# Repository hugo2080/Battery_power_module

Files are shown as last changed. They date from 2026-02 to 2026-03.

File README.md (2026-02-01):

# Battery_power_module



Battery power module for bathroom scale

Place a 0.7 V forward voltage rectifier diode, e.g. 1N4007, between pin 2 of connector J2 and VDD of the MCU board, with the anode facing J2, to reduce the voltage to a safe 3.6 V.

## Licensing

This project is released under the **CERN Open Hardware Licence v1.2**.

* **Hardware Documentation:** Licensed under the terms of CERN OHL v.1.2. See `cern_ohl_v_1_2.txt` for the full license text.
* **Software/Firmware:** none.
* **Documentation Location:** https://github.com/hugo2080/Battery_power_module

> **Note:** As per the license requirements, any redistribution or modification of this project must retain the original copyright notices and the license text.

## Repository Structure

Based on the project configuration, the files are organized as follows:

* `/hardware` – KiCad source files (`.kicad_sch`, `.kicad_pcb`).
* `/datasheets` – Placeholder for component datasheets (this folder is empty due to manufacturer copyrights; please download them manually for your own use).
* `/software` – Firmware source code and scripts.
* `CHANGES.TXT` – A log of modifications (required by CERN OHL).
* `PRODUCT.TXT` – Contact information for the author and potential manufacturers.

## Technical Requirements

* **PCB Design:** KiCad (version 9.0 or newer recommended).
* **Firmware/Software:** none.

## Getting Started

1.  **Clone the repository:** `git clone https://github.com/hugo2080/Battery_power_module`
2.  **Open the hardware project:** Navigate to the `/hardware` folder and open the `.kicad_pro` file in KiCad.
3.  **Prepare for assembly:** Refer to the Bill of Materials (BOM) and download the necessary datasheets into the `/datasheets` folder.

## Disclaimer

This documentation is distributed **WITHOUT ANY EXPRESS OR IMPLIED WARRANTY**, including of merchantability, satisfactory quality, and fitness for a particular purpose. Use this hardware at your own risk. Please see the CERN OHL v.1.2 for applicable conditions.

---
Copyright hugo2080 2025

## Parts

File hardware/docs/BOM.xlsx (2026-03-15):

Reference | Qty | Value | DNP | Exclude from BOM | Exclude from Board | Footprint | Datasheet
C1,C2 | 2 | 1u |  |  |  | Capacitor_SMD:C_0603_1608Metric | ~
D1 | 1 | GREEN |  |  |  | LED_SMD:LED_0805_2012Metric | ~
D2 | 1 | RED |  |  |  | LED_SMD:LED_0805_2012Metric | ~
D3 | 1 | D_TVS |  |  |  | Diode_SMD:D_SMB | ~
J1 | 1 | USB_C_Receptacle_PowerOnly_6P |  |  |  | Connector_USB:USB_C_Receptacle_GCT_USB4125-xx-x-0190_6P_TopMnt_Horizontal | https://www.usb.org/sites/default/files/documents/usb_type-c.zip
R1,R2 | 2 | 1,5k |  |  |  | Resistor_SMD:R_0603_1608Metric | ~
R3 | 1 | 1k |  |  |  | Resistor_SMD:R_0603_1608Metric | ~
R4 | 1 | 2k |  |  |  | Resistor_SMD:R_0603_1608Metric | ~
R5,R6 | 2 | 5,1k |  |  |  | Resistor_SMD:R_0603_1608Metric | ~
TH1 | 1 | Thermistor_NTC |  |  |  | Resistor_THT:R_Axial_DIN0207_L6.3mm_D2.5mm_P2.54mm_Vertical | ~
U1 | 1 | BQ24090DGQ |  |  |  | Package_SO:HVSSOP-10-1EP_3x3mm_P0.5mm_EP1.57x1.88mm_ThermalVias | http://www.ti.com/lit/ds/symlink/bq24090.pdf

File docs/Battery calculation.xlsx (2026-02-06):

Manufacturer Part No. | Capacity (mAh) | Dimensions (LxWxH) (mm) | Price (zł) | Capacity to price ratio (mAh/zł) | Comments:
AKY0128 | 220 | 38,5x21x4,5 | 12.46 | 17.7 | If any of the dimensions was greater than or equal to 54x28x10 (LxWxH), Manufacturer Part No. was marked in red.
AKY0384 | 250 | 32,5x18x6,5 | 12.46 | 20.1
AKY0385 | 270 | 47,5x28x4 | 13.53 | 20.0 | After elimination:
AKY0106 | 250 | 32,5x21x5,5 | 13.53 | 18.5 | Manufacturer Part No. | Capacity (mAh) | Dimensions (LxWxH) (mm) | Price (zł) | Capacity to price ratio (mAh/zł)
AKY0300 | 320 | 42,5x31x3,5 | 13.93 | 23.0 | AKY0128 | 220 | 38,5x21x4,5 | 12.46 | 17.7
AKY0822 | 400 | 43,5x35x3,4 | 14.1 | 28.4 | AKY0384 | 250 | 32,5x18x6,5 | 12.46 | 20.1
AKY0486 | 450 | 50,5x23x5,5 | 15.54 | 29.0 | AKY0106 | 250 | 32,5x21x5,5 | 13.53 | 18.5
AKY0386 | 400 | 35,5x30x4 | 15.75 | 25.4 | AKY0486 | 450 | 50,5x23x5,5 | 15.54 | 29.0
AKY0646 | 1100 | 55,5x32x6 | 16.18 | 68.0 | AKY0657 | 300 | 32,5x21x8 | 16.18 | 18.5
AKY0657 | 300 | 32,5x21x8 | 16.18 | 18.5 | AKY0823 | 500 | 39,5x24x5,9 | 17.61 | 28.4
AKY0185 | 550 | 42,5x31x5,5 | 16.32 | 33.7 | AKY0972 | 360 | 47,5x18x5,5 | 19.44 | 18.5
AKY0392 | 800 | 50,5x33x4,5 | 16.47 | 48.6 | AKY0661 | 620 | 40,5x20x8,5 | 20.98 | 29.6
AKY0620 | 900 | 52,5x35x5,7 | 17.33 | 51.9
AKY0826 | 600 | 52,5x41x3,5 | 17.54 | 34.2 | Choice: AKY0823 because it has matching dimensions, more than twice the capacity of CR2032 and a high capacity to price ratio.
AKY0823 | 500 | 39,5x24x5,9 | 17.61 | 28.4
AKY0383 | 750 | 52,5x35x4,9 | 17.9 | 41.9
AKY0081 | 980 | 50,5x34x5,7 | 18.62 | 52.6
AKY0559 | 800 | 50,5x35x5,5 | 19.05 | 42.0
AKY0833 | 560 | 42,5x31x5,5 | 19.12 | 29.3
AKY0972 | 360 | 47,5x18x5,5 | 19.44 | 18.5
AKY0655 | 750 | 58,5x21x6 | 20.26 | 37.0
AKY0108 | 850 | 48,5x30x6 | 20.98 | 40.5
AKY0661 | 620 | 40,5x20x8,5 | 20.98 | 29.6
AKY0622 | 1200 | 40,5x34x8,8 | 21.77 | 55.1
AKY0662 | 1050 | 37,5x31x10,5 | 23.59 | 44.5
AKY0638 | 1200 | 50,5x34x6 | 24.7 | 48.6
AKY0658 | 1000 | 38,5x37x8 | 24.92 | 40.1
AKY0571 | 1000 | 40,5x30x8 | 24.92 | 40.1
AKY0099 | 1600 | 50,5x34x9 | 26.78 | 59.7

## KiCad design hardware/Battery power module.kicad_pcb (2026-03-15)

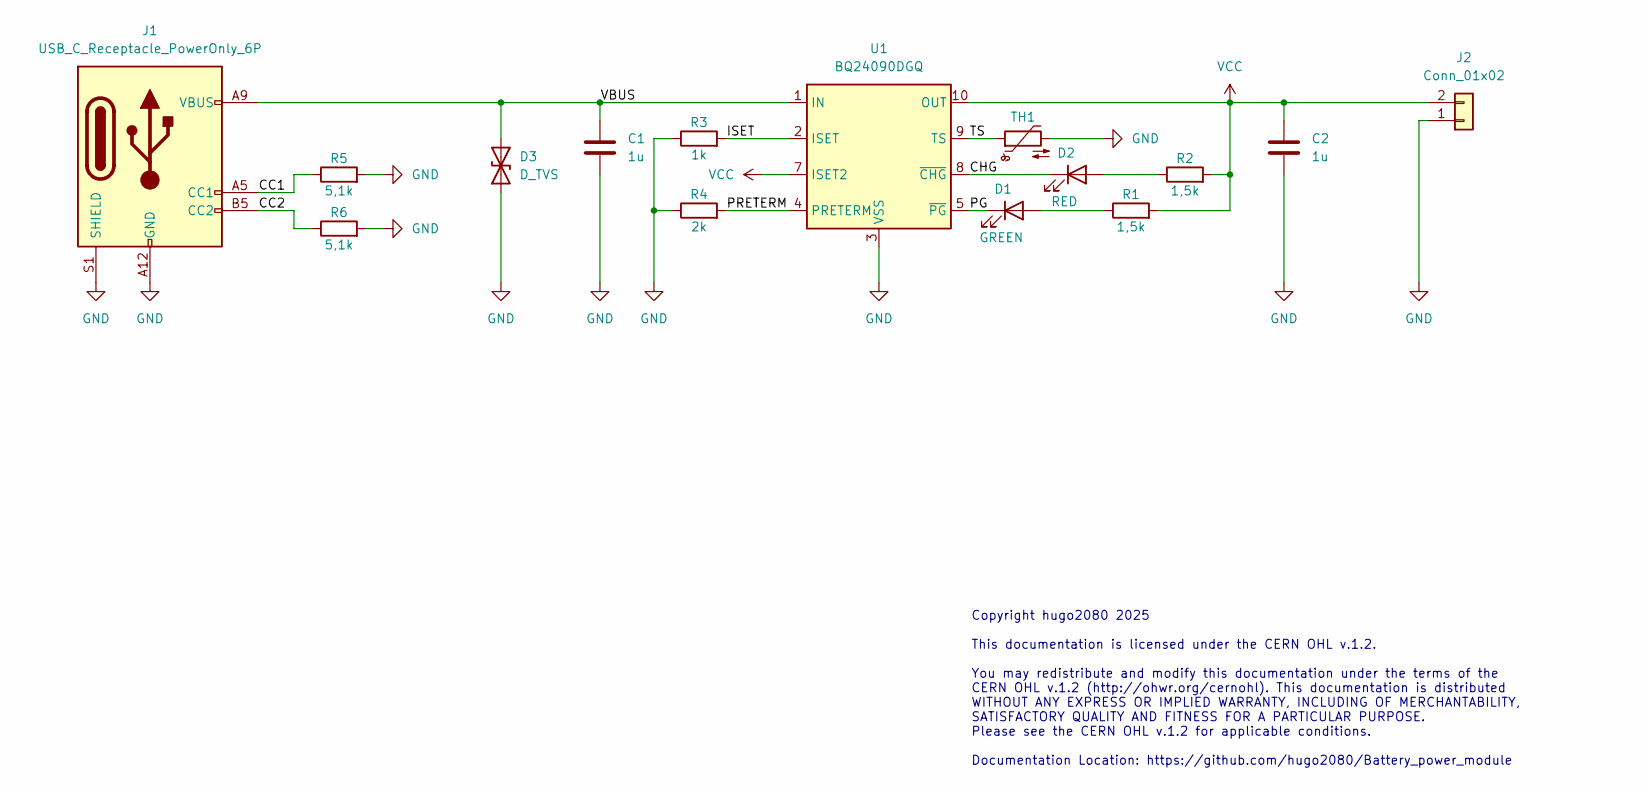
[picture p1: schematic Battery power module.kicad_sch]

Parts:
C1, C2: 1u; C_0603_1608Metric
D1: GREEN; LED_0805_2012Metric
D2: RED; LED_0805_2012Metric
D3: D_TVS; D_SMB
J1: USB_C_Receptacle_PowerOnly_6P; USB_C_Receptacle_GCT_USB4125-xx-x-0190_6P_TopMnt_Horizontal
J2: Conn_01x02; JST_PH_B2B-PH-K_1x02_P2.00mm_Vertical
R1, R2: 1,5k; R_0603_1608Metric
R3: 1k; R_0603_1608Metric
R4: 2k; R_0603_1608Metric
R5, R6: 5,1k; R_0603_1608Metric
TH1: Thermistor_NTC; R_Axial_DIN0207_L6.3mm_D2.5mm_P2.54mm_Vertical
U1: BQ24090DGQ; HVSSOP-10-1EP_3x3mm_P0.5mm_EP1.57x1.88mm_ThermalVias

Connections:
/CC1: J1.A5 (CC1), R5.1
/CC2: J1.B5 (CC2), R6.1
/CHG: D2.1 (K), U1.8 (~CHG)
/ISET: R3.2, U1.2 (ISET)
/PG: D1.1 (K), U1.5 (~PG)
/PRETERM: R4.2, U1.4 (PRETERM)
/TS: TH1.1, U1.9 (TS)
/VBUS: C1.1, D3.2 (A2), J1.A9 (VBUS), J1.B9 (VBUS), U1.1 (IN)
GND: C1.2, C2.2, D3.1 (A1), J1.A12 (GND), J1.B12 (GND), J1.S1 (SHIELD), J2.1, R3.1, R4.1, R5.2, R6.2, TH1.2, U1.3 (VSS), U1.11 (VSS)
unnamed: D1.2 (A), R1.1
unnamed: D2.2 (A), R2.1
VCC: C2.1, J2.2, R1.2, R2.2, U1.7 (ISET2), U1.10 (OUT)

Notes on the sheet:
Copyright hugo2080 2025 This documentation is licensed under the CERN OHL v.1.2. You may redistribute and modify this documentation under the terms of the CERN OHL v.1.2 (http://ohwr.org/cernohl). This documentation is distributed WITHOUT ANY EXPRESS OR IMPLIED WARRANTY, INCLUDING OF MERCHANTABILIT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

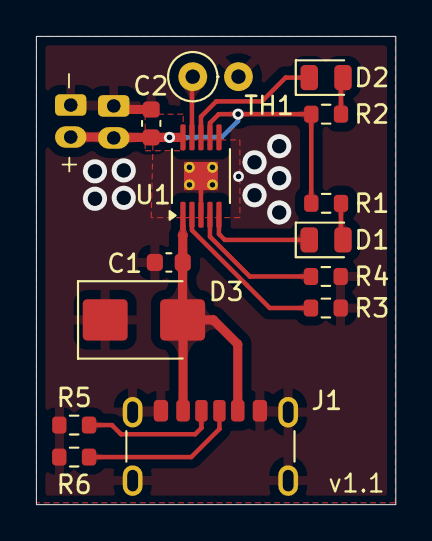
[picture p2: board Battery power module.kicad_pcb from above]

Board: 2 copper layers, 20.0 x 26.0 mm, 14 parts (0 on the bottom side), 12 nets.

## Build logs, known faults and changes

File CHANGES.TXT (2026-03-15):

This file is for describing modifications made by the Licensee, see section 3.4.b of the CERN OHL license.

01-02-2026: Initial version (v1.0).
15-03-2026: Extending the USB port beyond the board outline and adding a version designation on the PCB (v1.1).

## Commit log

2026-02-01 Version 1.0: Hardware files and CERN OHL v1.2 license
    [Battery power module-B_Cu.gbr, Battery power module-B_Mask.gbr, Battery power module-B_Paste.gbr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]
2026-02-06 Add Battery calculation sheet
    [Battery calculation.xlsx]
2026-02-23 Add BOM
    [BOM.xlsx]
2026-03-15 Version 1.1: Extending the USB port beyond the board outline and adding a version designation on the PCB
    [BOM.xlsx, Battery power module.kicad_pcb, Battery power module.kicad_sch]

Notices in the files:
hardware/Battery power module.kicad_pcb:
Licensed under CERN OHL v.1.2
